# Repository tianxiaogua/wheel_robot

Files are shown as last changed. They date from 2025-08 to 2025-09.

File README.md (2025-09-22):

# wheel_robot
robot

[YOLOE+树莓派5，无需训练的新一代计算机视觉！](https://mp.weixin.qq.com/s/UgIYmbcPV5UVZVgWxDwPNA)

# FOC

编写foc控制代码

参考：

[如何从零开始写一套自己的FOC矢量控制程序 - 知乎 (zhihu.com)](https://zhuanlan.zhihu.com/p/103758450)

[从零开始自己编写FOC 算法篇：FOC和SVPWM_哔哩哔哩_bilibili](https://www.bilibili.com/video/BV1wP4y167ao/?spm_id_from=333.788&vd_source=c13bbf05d4b570439590d88626eb3093)

[最小FOC矢量控制系统所需的基本模块和功能配置 - 知乎 (zhihu.com)](https://zhuanlan.zhihu.com/p/667327043)

[GitHub - chenzt2020/foc_learning](https://github.com/chenzt2020/foc_learning/tree/main)

[FOC?看这篇文章就够了 - 知乎 (zhihu.com)](https://zhuanlan.zhihu.com/p/364247816)

[正点原子电机笔记——FOC入门 - 知乎 (zhihu.com)](https://zhuanlan.zhihu.com/p/654633911#:~:text=实际PID控制只使用了PI控制，没有引入微分控制，因为 电流的采样率非常高，不需要加入微分项,。 FOC目的 Iq是需要的，代表了期望的力矩输出；Id是不需要的，尽可能控制为零！)

[ svpwm - 知乎 (zhihu.com)](https://www.zhihu.com/search?type=content&q=svpwm)

[FOC项目知识点总结三 | 完全搞懂 Clarke 与 Park 变换（附动图，仿真文件以及详细讲解数学推导过程）_clarke park-CSDN博客](https://blog.csdn.net/weixin_43229030/article/details/115190315)

[STM32 进阶教程 19 - IQmath数学库的使用-CSDN博客](https://blog.csdn.net/zhanglifu3601881/article/details/97617417)

[数字电路设计（30）之电流检测(含计算)_stm32 10a电流检测-CSDN博客](https://blog.csdn.net/qq_37120496/article/details/133471283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)

[foc学习笔记3——电流环_foc电流环-CSDN博客](https://blog.csdn.net/jdhfusk/article/details/120646346)

[【电机控制】PMSM无感FOC控制（一）FOC入门_foc有感、无感无刷电机控制-CSDN博客](https://blog.csdn.net/Liu_eight_nine/article/details/132448058)



### **FOC目的**



**Iq是需要的，代表了期望的力矩输出；Id是不需要的，尽可能控制为零！！**

仔细观察我们可以发现，当三相绕组产生的磁场方向始终与转子磁铁相切的时候最为理想，这样相同电流下产生的旋转力量最大（图中IQ），当我们三相绕组产生的磁场方向与转子磁场方向反向平行时，这时候电机会被吸在原地不动(图中ID)，电流都用来产生热量。因此我们以转子磁铁为参考，建立DQ坐标系，DQ坐标系随转子转动。(备注：为了便于理解我对磁铁进行了放大)

如图当我们让ID为0, IQ为1则转子就会逆时针旋转，且转速随着IQ的变大而变大。 如图当我们让ID为1, IQ为0则转子就会定在原地，且发热量随着ID的变大而变大。 因此可以总结一下，要想让转子平稳的转动下去就需要让三相绕组产生的磁场方向一直和转子磁铁的磁场方向垂直，即图中的IQ, 同时使ID尽可能为0以减小发热。那么怎么让绕组产生的磁场方向等效为IQ ID呢由此变引入Park反变换和Clark反变换。

**坐标变换可以采用全浮点实现，也可以采用标幺化处理，以 Q15 格式进行运算，三角函数可以采用查表实现，减少运算复杂度，节省运算时间。**

SVPWM 的实现一般涉及到硬件 PWM 模块的配置，矢量合成扇区的判断以及作用时间的计算等，常采用 STM32 的两个高级定时器 TIM1 和 TIM8 实现。高级定时器相对于通用定时器添加了可编程死区、重复计数器以及刹车等功能。

因为要产生互补对称的方波， PWM 定时器一般设置为中央对齐模式，且需要加入一定时间的死区，防止同一桥臂上的上下两个 MOS 管同时导通，造成系统短路。

[M法、T法以及M/T法测速原理概述 - 知乎 (zhihu.com)](https://zhuanlan.zhihu.com/p/105165951)

最后实现 FOC 矢量控制两个大的任务模块，一个是 FOC 核心算法，这个核心算法需要在每个 FOC 执行周期中执行一次，一般放到 ADC 中断中执行；另外一个任务模块负责状态机的轮询和系统保护，这个模块通常放在系统滴答定时器中断中。

完成以上模块基本上可以实现一个 FOC 的最小控制系统，当然为了调试方便，可以配置 DAC 功能、USART 功能、CAN 功能等等。

**Iq是需要的，代表了期望的力矩输出；Id是不需要的，尽可能控制为零！！**

### **速度+电流环**



Speed_Ref代表期望转速，而ω是电机转速；
将**速度环的输出，作为电流环的输入**，实现速度+电流的双闭环控制！

所以为了避免速度环节带来的误差，在做位置控制的时候可以只使用位置和电流组成的双环进行控制，不过此时需要对位置环做一定的变化，控制框图如下：



位置-电流双闭环控制

由于去掉了速度环，这里的位置环我们使用完整的**PID控制**，即把微分项加上（因为位置的微分就是速度，这样可以减小位置控制的震荡加快收敛；积分项的作用是为了消除静态误差）。

## 应用

[【自动驾驶】运动规划丨速度规划丨T型/S型速度曲线 - 知乎 (zhihu.com)](https://zhuanlan.zhihu.com/p/453670719)

S型曲线加速

[SimpleFOC（八）—— 理论+实践 深度分析SVPWM_svpwm的原理及法则推导和控制算法详解-CSDN博客](https://blog.csdn.net/loop222/article/details/117468766)

[手把手教你为DC/DC转换器选择电感和电容 - 知乎 (zhihu.com)](https://zhuanlan.zhihu.com/p/145217274)

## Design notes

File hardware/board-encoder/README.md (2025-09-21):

# foc encoder HV 1.1 2024.8.25

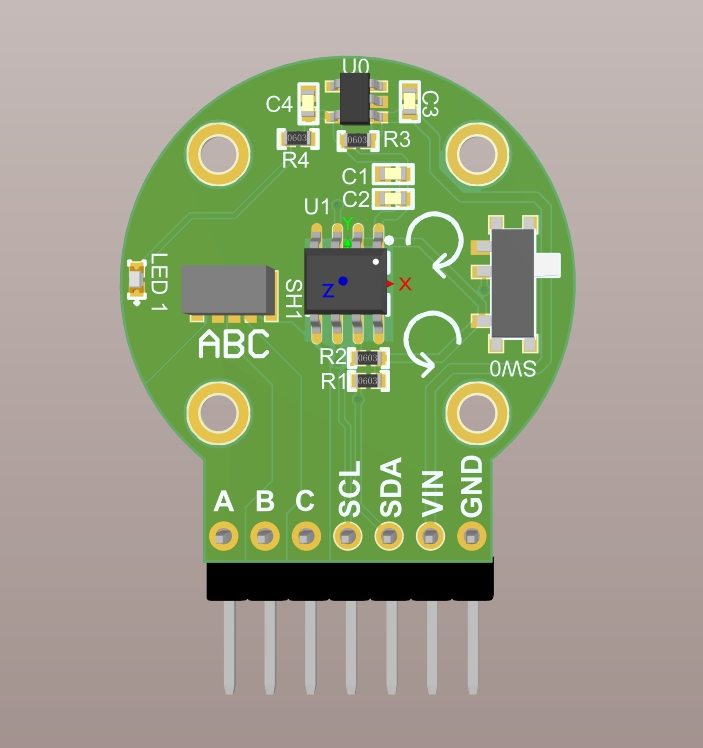
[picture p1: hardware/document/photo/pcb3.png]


## 设计实现

1、使用更兼容的2.54接口作为板件通信方案；

2、自带LDO电源，避免干扰问题；

3、添加板上可设置的开关；

## 存在问题

1、下一版本PCBA直接放在主板上作为一张板子；

2、PCB上的打孔使用长条的形状可以适配更多的电机；

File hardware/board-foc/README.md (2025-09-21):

# 设计需求

1、设计一个轮足机器人；

2、机器人有车轮和一组可以活动的关节组成，分别是一对行走的轮子和用来作为关节的步进电机；

3、提供一定的续航能力，不需要太久，可以使用十分钟就可以了；

4、机器人顶部提供可以拓展的接口，可以用来控制机器人的运动；

5、机器人的内部需要具有拓展性，设计是分为FOC的轮子驱动板和负责运动部分的辅助板；

6、具备遥控的能力；

# foc HV 0.3 2024.8.25

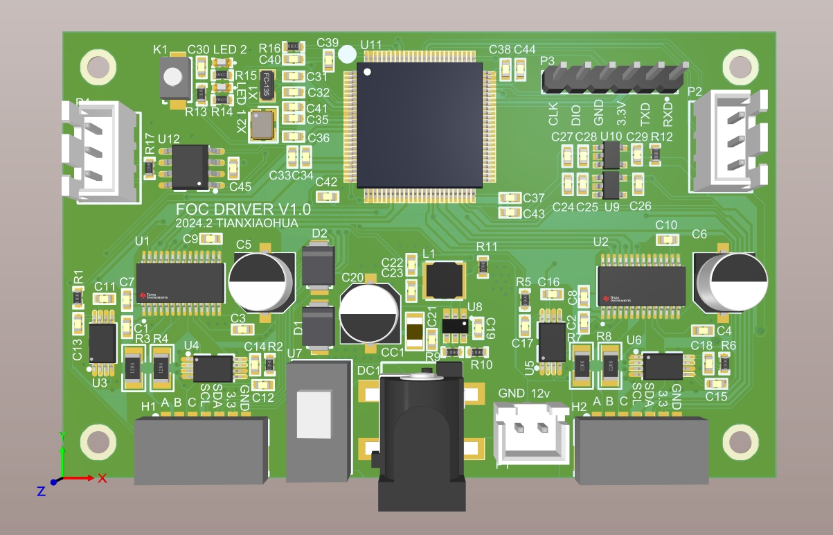
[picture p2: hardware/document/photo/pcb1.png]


## 设计实现

1、完成FOC驱动，可通过串口控制；

2、电源部分正常；

## 存在问题

1、单片机过大，更换小尺寸PCB和单片机，适配新的硬件结构；

2、去掉can总线驱动；

# foc HV 0.4 2024.9.1

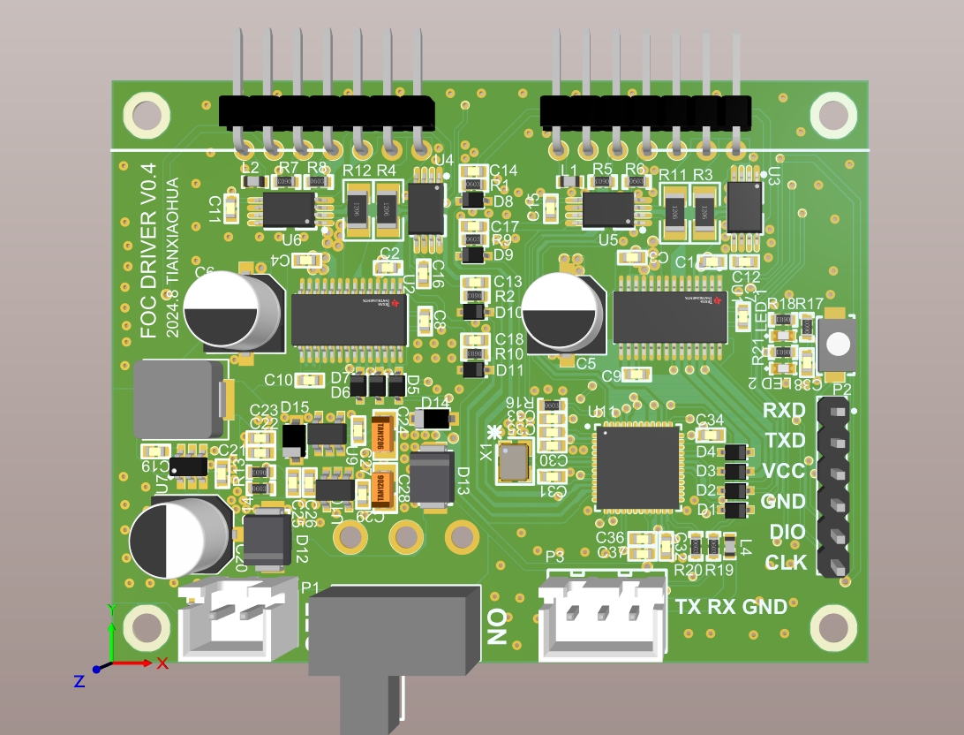
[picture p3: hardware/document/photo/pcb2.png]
 

## 设计实现

1、更换更稳定的外部接口，使用2.54接口适配更广

2、兼容板件连接件；

3、使用更紧凑的PCBA；

4、直接使用串口作为板间通信方案；

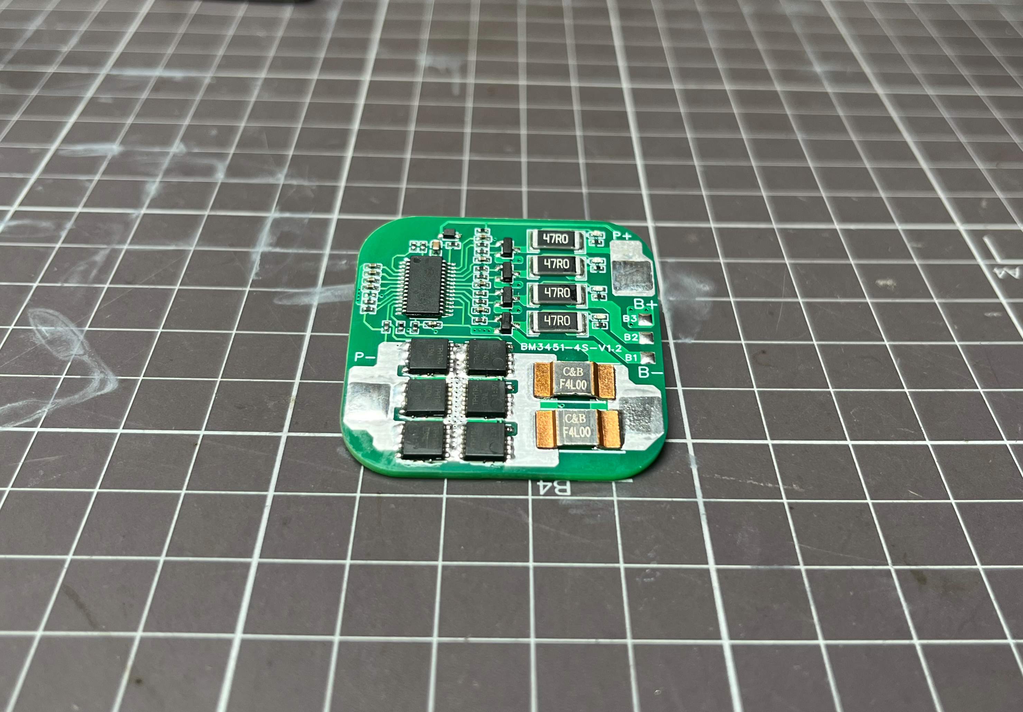
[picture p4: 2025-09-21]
hardware/document/hAonNuIqSdg4gnzpj3wqrscbwUsK1bf6QsZOEKpe.jpeg

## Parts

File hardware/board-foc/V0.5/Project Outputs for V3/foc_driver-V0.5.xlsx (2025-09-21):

Comment | Description | Designator | Footprint | LibRef | Quantity
16V 220uF | 铝点解电容 | C35, C39 | CAP-SMD_D6.3 | Cap ECAP SMD | 2
35V 100UF | 铝点解电容 | C5, C6 | CAP-SMD_D6.3 | Cap ECAP SMD | 2
0.01UF | 0603封装的电容, 贴片电容 | C7, C8, C36 | CC1608-0603 | Cap Chip 0603, Chip capacitor | 3
0.47UF | 0603封装的电容 | C9, C10 | CC1608-0603 | Cap Chip 0603 | 2
1UF | 0603封装的电容 | C25, C27, C29 | CC1608-0603 | Cap Chip 0603 | 3
2.2NF | 0603封装的电容 | C13, C14, C17, C18 | CC1608-0603 | Cap Chip 0603 | 4
2.2UF | 贴片电容, 0603封装的电容 | C33, C40, C44 | CC1608-0603 | Chip capacitor, Cap Chip 0603 | 3
4.7UF 50V | 贴片电容 | C37, C38 | CC1608-0603 | Chip capacitor | 2
10UF | 0603封装的电容 | C28 | CC1608-0603 | Cap Chip 0603 | 1
12PF | 0603封装的电容 | C19, C20 | CC1608-0603 | Cap Chip 0603 | 2
22UF | 贴片电容 | C42, C46 | CC1608-0603 | Chip capacitor | 2
100NF | 0603封装的电容, 贴片电容 | C1, C2, C3, C4, C11, C12, C15, C16, C21, C22, C23, C24, C26, C30, C31, C32, C34, C41, C43, C45, C47 | CC1608-0603 | Cap Chip 0603, Chip capacitor | 21
0R | 贴片电阻, 0603封装电阻 | R25, R28, R29 | CR1608-0603 | Chip resistor, Resistor Chip 0603 | 3
2K | 0603封装电阻 | R15, R18 | CR1608-0603 | Resistor Chip 0603 | 2
3.24K 1% | 贴片电阻 | R27 | CR1608-0603 | Chip resistor | 1
10K | 0603封装电阻, 贴片电阻 | R12, R13, R19, R20, R21, R22, R23, R24 | CR1608-0603 | Resistor Chip 0603, Chip resistor | 8
10K 1% | 贴片电阻 | R26 | CR1608-0603 | Chip resistor | 1
10R | 0603封装电阻 | R14 | CR1608-0603 | Resistor Chip 0603 | 1
22R | 0603封装电阻 | R1, R2, R7, R8, R16, R17 | CR1608-0603 | Resistor Chip 0603 | 6
0.01R | 1206封装电阻 | R3, R4, R9, R10 | CR3216-1206 | Resistor Chip 1206 | 4
B340A | 40V 3A 550mV@3A | D1 | DO-214 AA | B340A | 1
SS34 | 肖特基二极管 | D2 | DO-214 AA | SS34 | 1
GT-24-MINI | 工业级GT-24数传无线模块 2.4G NRF24L01&PA+LNA | MK1 | GT24 _MINI | GT-24-MINI | 1
Header 3 | Header, 3-Pin | P3, P4, P5, P6 | HDR1X3 | Header 3 | 4
Header 6 | Header, 6-Pin | P1 | HDR1X6 | Header 6 | 1
Header_2P_Curved | 弯的2P排针 | H3, H4 | Header_2_54_2PW | Header_2P_Curved | 2
Header_3P_Curved | 弯的3P排针 | H0 | Header_2_54_3PW | Header_3P_Curved | 1
DRV8313PWPR | 独立控制的半 H 桥驱动器,主要用于驱动一个三项无刷电机IC MOTOR DRIVER 8V-60V 28HTSSOP | U1, U2 | HTSSOP-28 | DRV8313 | 2
68nH 200mA | 贴片电感 0603封装 | L1, L2, L3 | Inductor-0603 | Inductor-0603 | 3
22UH | 1040封装 一体成型 贴片 功率电感 | L4 | Inductor-1040 | Inductor-1040 | 1
KEY 3*4 | 轻触开关按键 | K1 | KEY 3*4 | KEY 3*4 | 1
LED 0603 |  | LED 1, LED 2 | LED 0603 | LED 0603 | 2
STM32G431RBT6 |  | U7 | LQFP-64 | STM32G431RBT6 | 1
MPU6050 | 陀螺仪 | U8 | QFN24 - duplicate | MPU6050 | 1
0R | 0603封装电阻 | R5, R6 | SMD_0603-8P | Resistor Chip 0603_1206 | 2
4.7K | 0603封装电阻 | R11 | SMD_0603-8P | Resistor Chip 0603_1206 | 1
TPS5430DDAR | 宽电压DCDC降压IC | U9 | SOIC-8-E | TPS5430DDAR | 1
SPX3819M5-L-3.3/TR | LDO 3.3V , SOT-23-5 500ma | U11, U12 | SOT23-5 | SPX3819M5-L-3.3/TR | 2
HX SS12D10G4 |  | U10 | SW-TH_3P-SS12D06 | SW-TH_3P-SS12D06 | 1
test | 测试点 | GND, GND1, P5V, PGND3, RX1, TX1, VDDP | test | test | 7
INA240A1PWR | 超精密电流检测放大器 | U3, U4, U5, U6 | TSSOP-8 | INA240A1PWR | 4
3225_8M | 3225封装的晶振 | X1 | XTAL-3225 | XTAL 3225 | 1
ZH 1.5-7P | ZH1.5-7P 间距1.5的贴片连接座 | H1, H2 | ZH1.5-7P | ZH 1.5-7P | 2

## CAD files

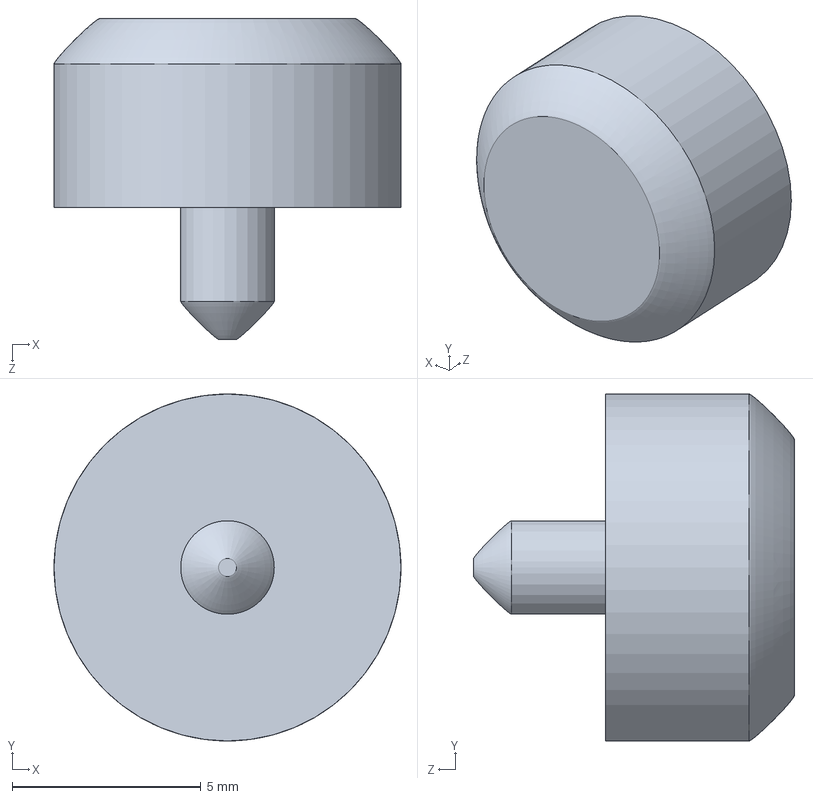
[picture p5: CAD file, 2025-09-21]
hardware/3D/无刷电机磁铁连接件.SLDPRT
9.20 x 9.20 x 8.50 mm

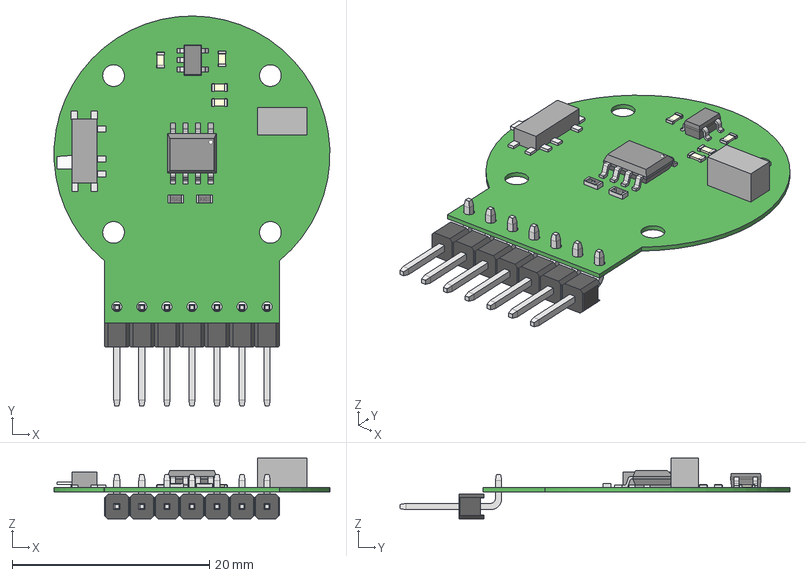
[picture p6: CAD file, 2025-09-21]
hardware/board-encoder/V1.1/PCB.step
28.0 x 39.6 x 6.16 mm
HEADER_2_54_HORIZONTAL_2X x 4
Free-Models003
Extruded x 10
CC0603 x 4
R0603 x 2
User_Library-SOIC_N-R8

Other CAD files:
hardware/3D/无刷电机磁铁连接件.STL

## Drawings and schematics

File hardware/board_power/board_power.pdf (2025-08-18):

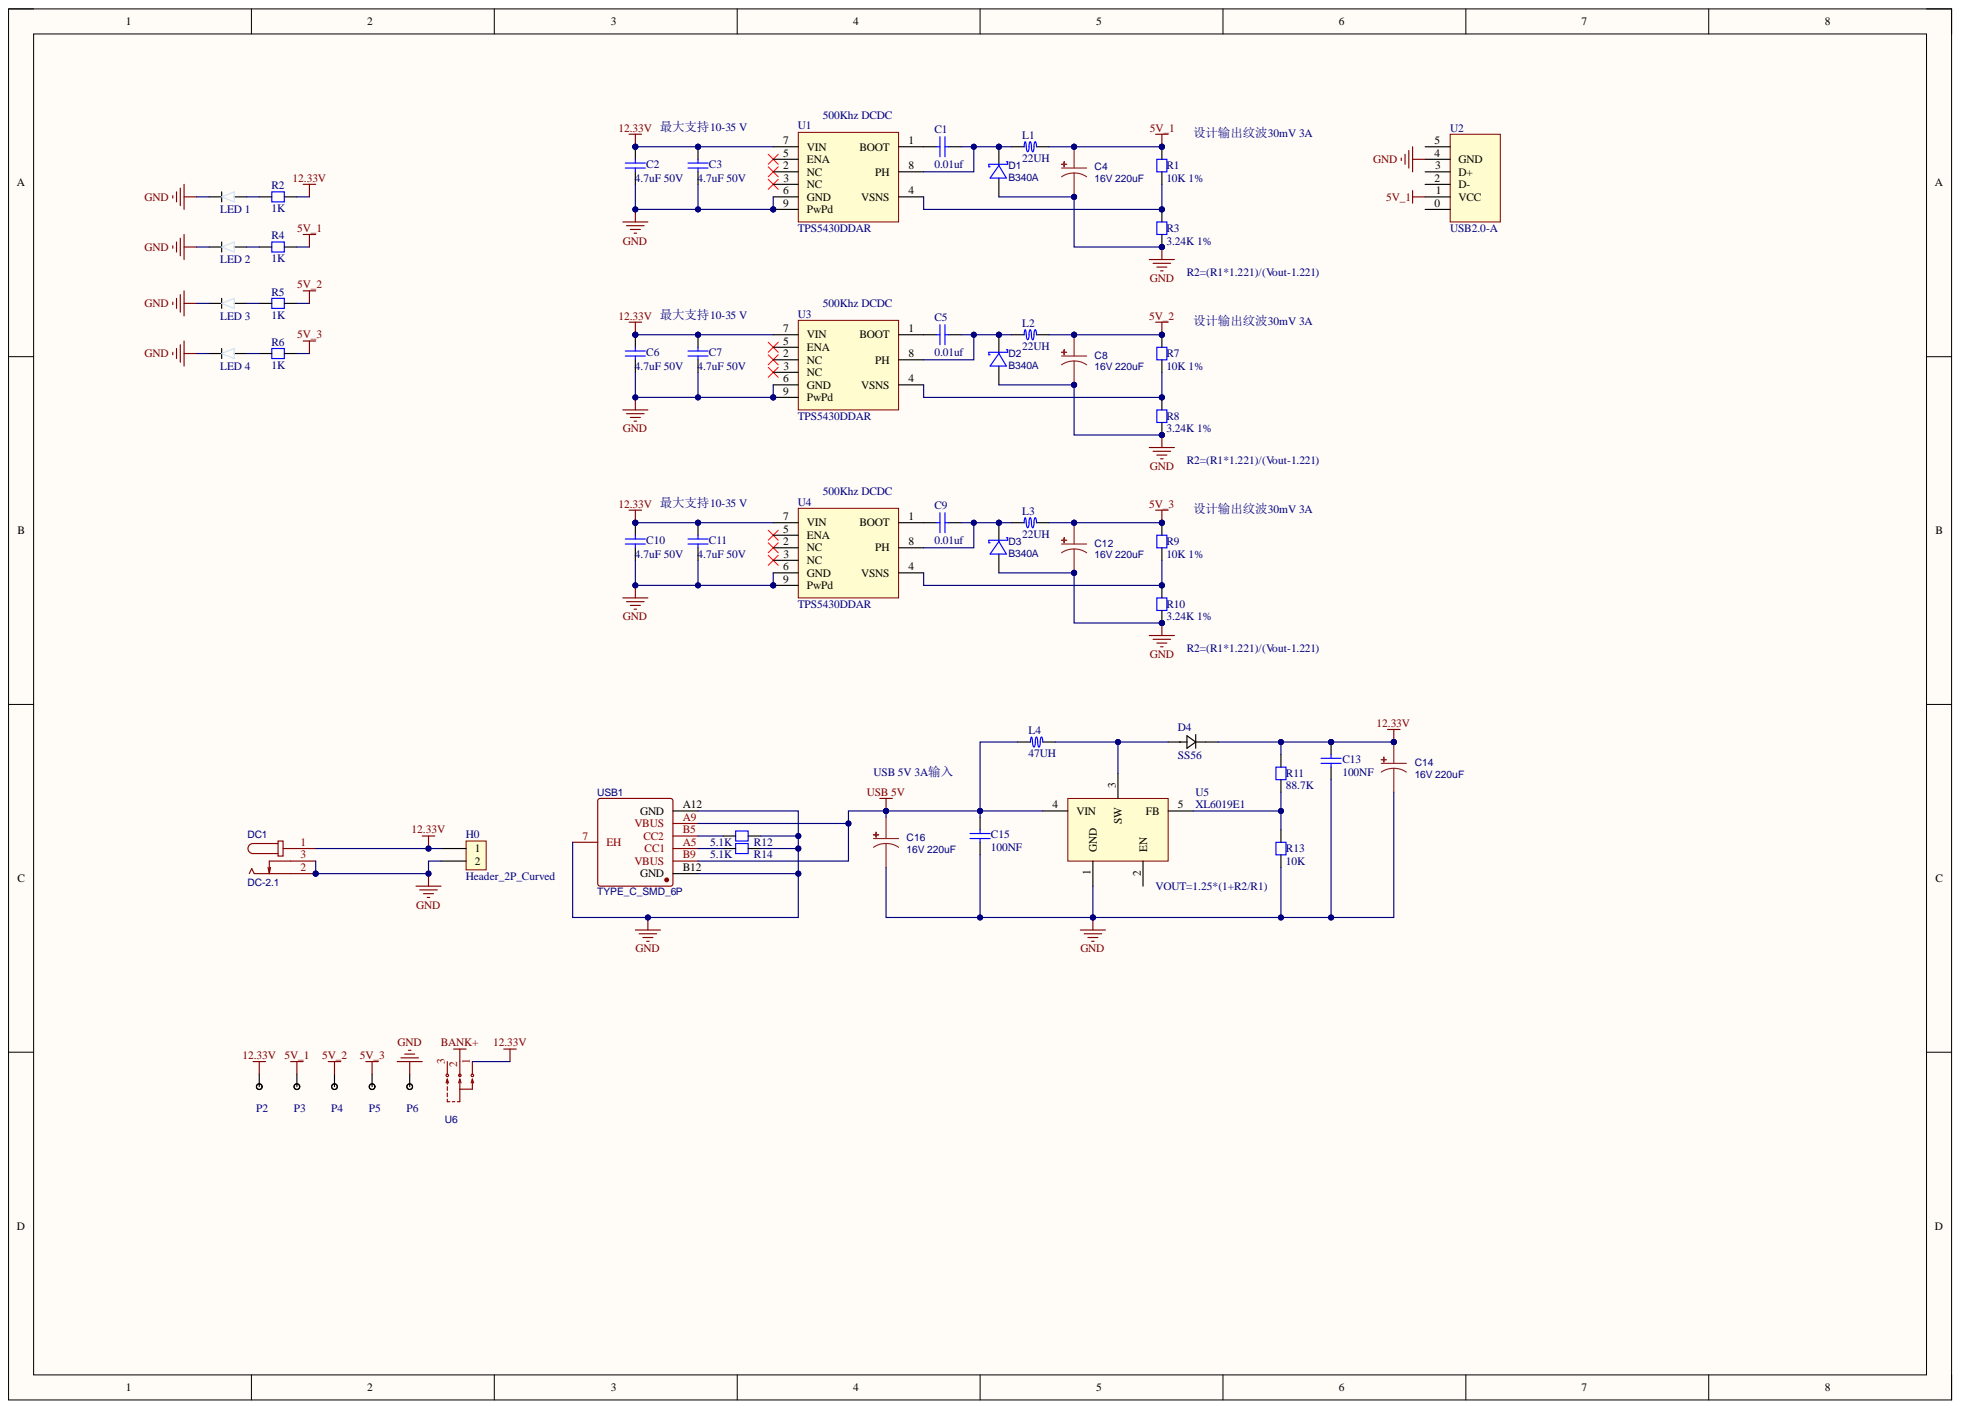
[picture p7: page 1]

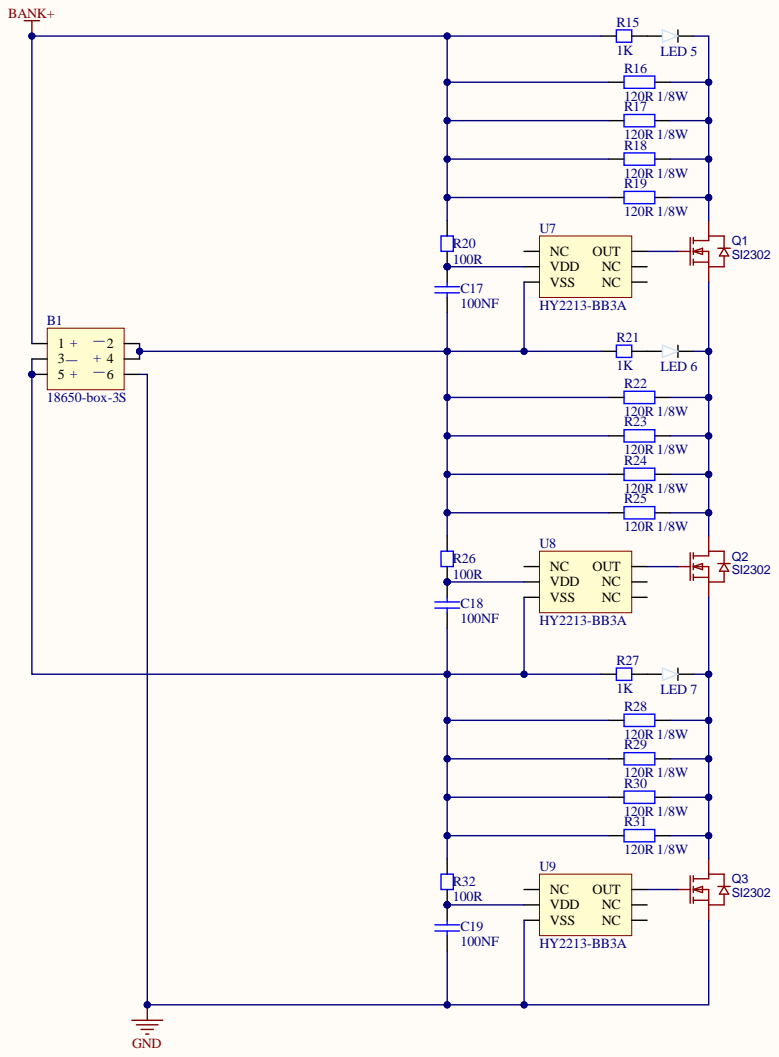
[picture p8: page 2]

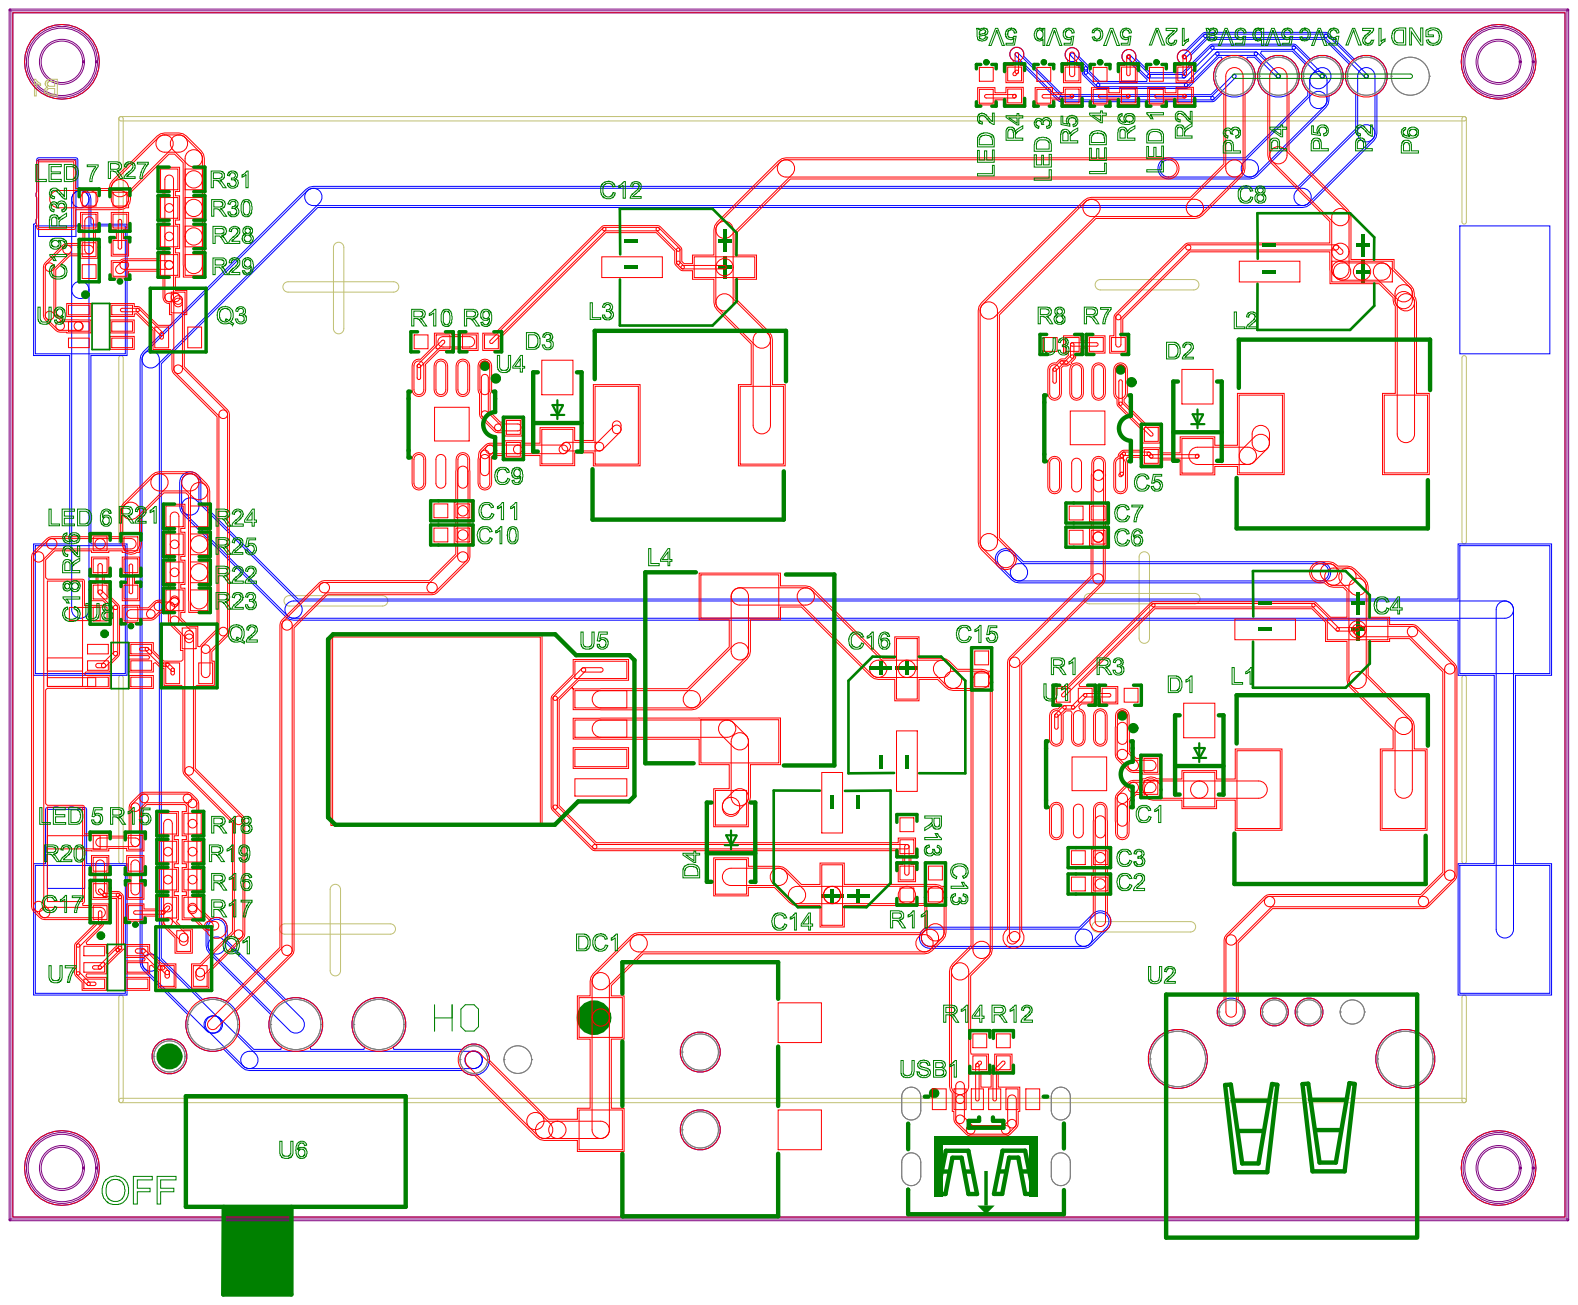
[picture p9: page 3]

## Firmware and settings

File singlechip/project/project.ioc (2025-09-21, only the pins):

Mcu.UserName=STM32G431RBTx
PA0.Signal=ADC1_IN1
PA1.Signal=ADC1_IN2
PA10.Signal=USART1_RX
PA11.Signal=S_TIM4_CH1
PA12.Signal=S_TIM4_CH2
PA13.Signal=SYS_JTMS-SWDIO
PA14.Signal=SYS_JTCK-SWCLK
PA15.Signal=I2C1_SCL
PA2.Signal=ADC1_IN3
PA3.Signal=ADC1_IN4
PA4.Signal=S_TIM3_CH2
PA5.Signal=SPI1_SCK
PA6.Signal=SPI1_MISO
PA7.Signal=SPI1_MOSI
PA8.Signal=I2C2_SDA
PA9.Signal=USART1_TX
PB0.Signal=S_TIM3_CH3
PB14.Signal=S_TIM15_CH1
PB15.Signal=S_TIM15_CH2
PB3.Signal=USART2_TX
PB4.Signal=USART2_RX
PB7.Signal=I2C1_SDA
PC0.Signal=S_TIM1_CH1
PC1.Signal=S_TIM1_CH2
PC11.GPIO_Label=MPU_INT
PC11.Signal=GPIO_Input
PC12.GPIO_Label=GT24_IRQ
PC12.Signal=GPIO_Input
PC13.GPIO_Label=LCD0
PC13.Signal=GPIO_Output
PC14-OSC32_IN.Signal=RCC_OSC32_IN
PC15-OSC32_OUT.Signal=RCC_OSC32_OUT
PC2.Signal=S_TIM1_CH3
PC4.Signal=I2C2_SCL
PC5.GPIO_Label=SPI1_CS
PC5.Signal=GPIO_Output
PC6.Signal=S_TIM3_CH1
PC7.GPIO_Label=DRV_EN
PC7.Signal=GPIO_Output
PC8.Signal=I2C3_SCL
PC9.Signal=I2C3_SDA
PD2.GPIO_Label=GT24_CE
PD2.Signal=GPIO_Output
PF0-OSC_IN.Signal=RCC_OSC_IN
PF1-OSC_OUT.Signal=RCC_OSC_OUT

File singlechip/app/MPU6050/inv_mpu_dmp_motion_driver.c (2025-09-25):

/*
 $License:
    Copyright (C) 2011-2012 InvenSense Corporation, All Rights Reserved.
    See included License.txt for License information.
 $
 */
/**
 *  @addtogroup  DRIVERS Sensor Driver Layer
 *  @brief       Hardware drivers to communicate with sensors via I2C.
 *
 *  @{
 *      @file       inv_mpu_dmp_motion_driver.c
 *      @brief      DMP image and interface functions.
 *      @details    All functions are preceded by the dmp_ prefix to
 *                  differentiate among MPL and general driver function calls.
 */
#include <stdio.h>
#include <stdint.h>
#include <stdlib.h>
#include <string.h>
#include <math.h>
#include "inv_mpu.h"
#include "inv_mpu_dmp_motion_driver.h"
#include "dmpKey.h"
#include "dmpmap.h"
#include "usart.h"


//定义目标板采用MSP430
#define  MOTION_DRIVER_TARGET_MSP430

/* The following functions must be defined for this platform:
 * i2c_write(unsigned char slave_addr, unsigned char reg_addr,
 *      unsigned char length, unsigned char const *data)
 * i2c_read(unsigned char slave_addr, unsigned char reg_addr,
 *      unsigned char length, unsigned char *data)
 * delay_ms(unsigned long num_ms)
 * get_ms(unsigned long *count)
 */
#if defined MOTION_DRIVER_TARGET_MSP430
//#include "msp430.h"
//#include "msp430_clock.h"
#define delay_ms    HAL_Delay
#define get_ms      mget_ms
#define log_i 		printf
#define log_e  		printf

#elif defined EMPL_TARGET_MSP430
#include "msp430.h"
#include "msp430_clock.h"
#include "log.h"
#define delay_ms    msp430_delay_ms
#define get_ms      msp430_get_clock_ms
#define log_i       MPL_LOGI
#define log_e       MPL_LOGE

#elif defined EMPL_TARGET_UC3L0
/* Instead of using the standard TWI driver from the ASF library, we're using
 * a TWI driver that follows the slave address + register address convention.
 */
#include "delay.h"
#include "sysclk.h"
#include "log.h"
#include "uc3l0_clock.h"
/* delay_ms is a function already defined in ASF. */
#define get_ms  uc3l0_get_clock_ms
#define log_i       MPL_LOGI
#define log_e       MPL_LOGE

#else
#error  Gyro driver is missing the system layer implementations.
#endif

/* These defines are copied from dmpDefaultMPU6050.c in the general MPL
 * releases. These defines may change for each DMP image, so be sure to modify
 * these values when switching to a new image.
 */
#define CFG_LP_QUAT             (2712)
#define END_ORIENT_TEMP         (1866)
#define CFG_27                  (2742)
#define CFG_20                  (2224)
#define CFG_23                  (2745)
#define CFG_FIFO_ON_EVENT       (2690)
#define END_PREDICTION_UPDATE   (1761)
#define CGNOTICE_INTR           (2620)
#define X_GRT_Y_TMP             (1358)
#define CFG_DR_INT              (1029)
#define CFG_AUTH                (1035)
#define UPDATE_PROP_ROT         (1835)
#define END_COMPARE_Y_X_TMP2    (1455)
#define SKIP_X_GRT_Y_TMP        (1359)
#define SKIP_END_COMPARE        (1435)
#define FCFG_3                  (1088)
#define FCFG_2                  (1066)
#define FCFG_1                  (1062)
#define END_COMPARE_Y_X_TMP3    (1434)
#define FCFG_7                  (1073)
#define FCFG_6                  (1106)
#define FLAT_STATE_END          (1713)
#define SWING_END_4             (1616)
#define SWING_END_2             (1565)
#define SWING_END_3             (1587)
#define SWING_END_1             (1550)
#define CFG_8                   (2718)
#define CFG_15                  (2727)
#define CFG_16                  (2746)
#define CFG_EXT_GYRO_BIAS       (1189)
#define END_COMPARE_Y_X_TMP     (1407)
#define DO_NOT_UPDATE_PROP_ROT  (1839)
#define CFG_7                   (1205)
#define FLAT_STATE_END_TEMP     (1683)
#define END_COMPARE_Y_X         (1484)
#define SKIP_SWING_END_1        (1551)
#define SKIP_SWING_END_3        (1588)
#define SKIP_SWING_END_2        (1566)
#define TILTG75_START           (1672)
#define CFG_6                   (2753)
#define TILTL75_END             (1669)
#define END_ORIENT              (1884)
#define CFG_FLICK_IN            (2573)
#define TILTL75_START           (1643)
#define CFG_MOTION_BIAS         (1208)
#define X_GRT_Y                 (1408)
#define TEMPLABEL               (2324)
#define CFG_ANDROID_ORIENT_INT  (1853)
#define CFG_GYRO_RAW_DATA       (2722)
#define X_GRT_Y_TMP2            (1379)

#define D_0_22                  (22+512)
#define D_0_24                  (24+512)

#define D_0_36                  (36)
#define D_0_52                  (52)
#define D_0_96                  (96)
#define D_0_104                 (104)
#define D_0_108                 (108)
#define D_0_163                 (163)
#define D_0_188                 (188)
#define D_0_192                 (192)
#define D_0_224                 (224)
#define D_0_228                 (228)
#define D_0_232                 (232)
#define D_0_236                 (236)

#define D_1_2                   (256 + 2)
#define D_1_4                   (256 + 4)
#define D_1_8                   (256 + 8)
#define D_1_10                  (256 + 10)
#define D_1_24                  (256 + 24)
#define D_1_28                  (256 + 28)
#define D_1_36                  (256 + 36)
#define D_1_40                  (256 + 40)
#define D_1_44                  (256 + 44)
#define D_1_72                  (256 + 72)
#define D_1_74                  (256 + 74)
#define D_1_79                  (256 + 79)
#define D_1_88                  (256 + 88)
#define D_1_90                  (256 + 90)
#define D_1_92                  (256 + 92)
#define D_1_96                  (256 + 96)
#define D_1_98                  (256 + 98)
#define D_1_106                 (256 + 106)
#define D_1_108                 (256 + 108)
#define D_1_112                 (256 + 112)
#define D_1_128                 (256 + 144)
#define D_1_152                 (256 + 12)
#define D_1_160                 (256 + 160)
#define D_1_176                 (256 + 176)
#define D_1_178                 (256 + 178)
#define D_1_218                 (256 + 218)
#define D_1_232                 (256 + 232)
#define D_1_236                 (256 + 236)
#define D_1_240                 (256 + 240)
#define D_1_244                 (256 + 244)
#define D_1_250                 (256 + 250)
#define D_1_252                 (256 + 252)
#define D_2_12                  (512 + 12)
#define D_2_96                  (512 + 96)
#define D_2_108                 (512 + 108)
#define D_2_208                 (512 + 208)
#define D_2_224                 (512 + 224)
#define D_2_236                 (512 + 236)
#define D_2_244                 (512 + 244)
#define D_2_248                 (512 + 248)
#define D_2_252                 (512 + 252)
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

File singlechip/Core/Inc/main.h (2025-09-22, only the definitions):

#define High_band 460800
#define LED0_Pin GPIO_PIN_13
#define LED0_GPIO_Port GPIOC
#define SPI1_CS_Pin GPIO_PIN_5
#define SPI1_CS_GPIO_Port GPIOC
#define DRV_EN_Pin GPIO_PIN_7
#define DRV_EN_GPIO_Port GPIOC
#define MPU_INT_Pin GPIO_PIN_11
#define MPU_INT_GPIO_Port GPIOC
#define GT24_IRQ_Pin GPIO_PIN_12
#define GT24_IRQ_GPIO_Port GPIOC
#define GT24_CE_Pin GPIO_PIN_2
#define GT24_CE_GPIO_Port GPIOD

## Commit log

2025-08-18 支持电源板
    [PCB.PcbDoc, Sheet1-MCU.SchDoc, Sheet2-bms.SchDoc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]
2025-09-21 支持硬件
    [PCB.PcbDoc, PCB.step, Sheet.SchDoc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]
2025-09-22 foc驱动
2025-09-22 支持foc
2025-09-22 不适用电流环
2025-09-24 支持simpleFoc定速
2025-09-25 支持MPU外设
2025-09-28 支持定速旋转，支持MPU
2025-10-02 支持站立
2025-10-04 支持稳定直立
2025-10-06 支持控制角速度和线速度
2025-10-11 支持遥控

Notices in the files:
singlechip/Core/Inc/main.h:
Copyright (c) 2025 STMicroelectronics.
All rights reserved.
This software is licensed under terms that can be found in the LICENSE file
